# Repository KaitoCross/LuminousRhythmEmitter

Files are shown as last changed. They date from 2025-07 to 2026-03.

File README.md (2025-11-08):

# Future Gadget #16: Luminous Rhythm Emitter

## DIY Penlight project

### Description

This project is a work in progress! Use and build at your own risk! No guarantees given. Parts of the current version may be untested.
This project aims to create an open-source homemade penlight for various concerts (J-Pop, Idols, VTuber, Vocaloid) that can be controlled remotely. You'll need access to a 3D printer and equipment for soldering SMD parts. You'll have to order a PCB, based on the KiCad design provided in the `Circuits` folder, as well as some electronic parts. The `3D` folder contains the stl files for 3D printing. A parts list is located in the `Circuits` folder.

### Setup

[A brief How-To is located in `Circuits`](Circuits/README.md)

### Current Features

- Rechargable via USB-C
- Manual selection of LED color by pressing the button (cycling though a preset with 12 colors)
- Setting the color via (unsecured) Bluetooth Low Energy
- Separate Power Off switch

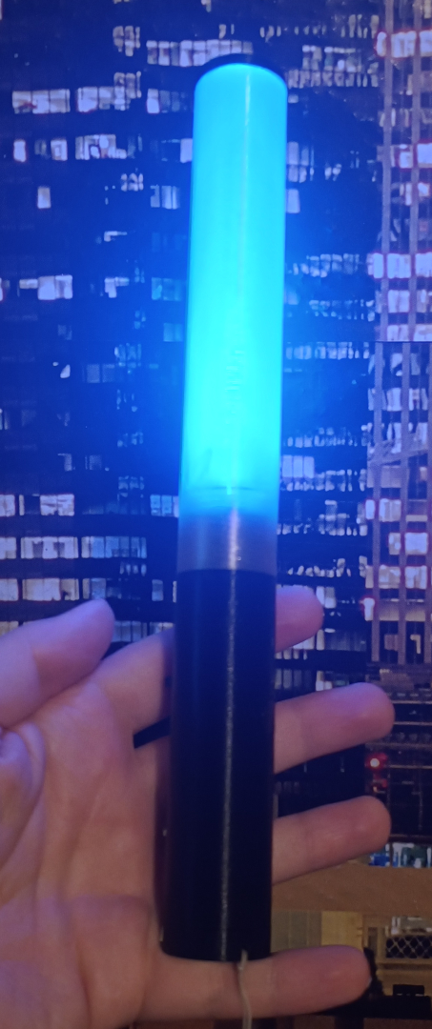
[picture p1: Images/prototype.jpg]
Prototype


### Shoutouts

Shoutouts to:

- rico132 (for helping with Fusion 360 and helping in fixing electronics)
- CaptainMeow (for the Otomo drawing on the PCB design)
- Dominik K (brainstormed the idea with me)
- KFP & the general VTubing community

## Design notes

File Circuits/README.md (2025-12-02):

# Hardware List:

- Seeed Studio XIAO ESP32C3
- power switch: MFP 120 by Knitter-Switch
- Any 18350 Li-ion battery with a **protection circuit** (preventing deep discharge)
- Button: generic 6x6x5mm pushbutton
- ~~20mm ø LED Lens (60°), max 11mm high~~
- screw the lens actually, it's better without
- The custom printed PCB
  - I recommend ordering the custom PCB through JLCPCB
- 2x 6-Pin 2.54mm Dupont female pin header (socket 8,5mm high)
- 2x 6-Pin 2.54mm Dupont male pin header (pin 6mm high)
- If PCB is not pre-assembled:
  - 1x Inolux IN-P55TATRGB
  - 3x S8050 (SMD type SOT-23)
  - SMD type 1206 resistors:
    - 3x 15,5 kOhm (or slightly lower)
    - 2x 11 Ohm (or slightly higher)
    - 1x 61 Ohm (or slightly higher)
- battery contacts (with spring)
- (optional) 100 mm 2,4 Ghz Antenna
- an LED light diffusion filter. Dimensions: 9,5cm x 14,5cm  (15.1mm inner cylinder radius)
  Recommendations: 
  - [Lee Colour Filter 251 (1/4 white diffusion)](https://www.thomann.de/intl/lee_colour_filter_251_q_w_diffus.htm)
  - [Lee Colour Filter 252 (1/8 white diffusion)](https://www.thomann.de/intl/lee_colour_filter_252_e_w_diffus.htm)

# How to Build

You’ll need to familiarize yourself with soldering SMD components.  
Required tools:

- SMD rework station

- Tweezers

- Solder paste and (preferably) no-clean flux

- Regular soldering iron and solder for through-hole parts

- [KiCAD](https://www.kicad.org/) (free & open-source) to open the circuit files

## XIAO ESP32C3

Start with the XIAO ESP32C3. Solder the male 6-pin headers to the board, aligning the 5V with the first pin of the pin header, with the long side of the pins on facing the same direction as the big chip. DO NOT USE 7-PIN headers! Solder the other male pin header exactly in parallel with the first one.s

## Custom PCB

Now you can start soldering the parts to the custom PCB. Start with the SMD parts, soldering them to their designated spots as marked on the board. Once that is done, solder the female pin headers to the board. They need to be on the side opposite to the LED.

## Battery wiring

Solder a red wire to the battery contact without the spring (positive battery pole). Thread the red wire through the centre hole of the 3D-printed battery wall. Then solder the other end of the red wire to the battery contact (positive pole) of the XIAO.

Solder a black wire to the negative battery contact pad of the XIAO. Solder the other end to the centre pin of the power switch. Solder another black wire from one of the outer pins of the power switch to the battery contact with the spring (negative). Ensure that this wire is long enough so that it can hang out of the bottom end (short thread) of the penlight case. Make it \~2 cm longer than the distance between USB port and bottom end.

## Pushbutton wiring

Connect two wires to the J4 holes on the PCB. Connect both wires to the pushbutton, one wire to the top right leg, the other one the the bottom right leg (see example image below)



## Assembly

3D-print all parts in the [`3D` folder](../3D). Print settings recommendations [are also provided.](../3D/print_settings.md) Some cutouts (mainly for the buttons) need to be sanded for a better fit.

Connect the PCB and the XIAO through the pin headers.

[Install the firmware on the XIAO](../Software/README.md) and test it.

Start with the half with the rectangular cutout on the top. Place the PCB on top of the Edge above the cutout, with the USB port facing the cutout. Place the black wire in the recess in the bottom. Then, but the battery wall in the space on the recess, aligning it with said recess, while the positive battery pole faces outward towards the bottom thread. 

To make working with the pushbutton easier, you need to straighten the unused legs, aligning them with the case of the button itself. Now, pull the pushbutton though the D-shaped hole, with the wires facing the wall. Place the button cap on the pushbutton. Put the rectangular power switch into it's holder near the XIAO.

Now, put the ~~lens~~ reflector into the ~~lens~~ reflector holder with the ~~flat~~ open side of the ~~lens~~ reflector facing the small end of the holder. Push it all the way in. Place the ~~lens~~ reflector holder on top of the PCB.

Now put the other half of the penlight base on top and close the case, making sure the buttons fit into the other half as well. Then you can screw on the top part. Into the top part, you can then place your light diffusion filter. You can then close the top part by screwing on the respective cap.

Now, you can place the battery in the battery compartment. Make sure that the positive pole faces inwards. The negative pole then faces outwards, and connects to the spring. hold the spring in place and close the battery compartment with the other, bigger cap.

Now you should be able to power on and use your penlight!

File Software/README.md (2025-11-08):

# Software

As a quick proof of concept, you can use [WLED](https://github.com/wled/WLED) to control the RGB LED on the ESP32 via WiFi. WLED does not offer Bluetooth support.
If you prefer Bluetooth Low Energy, I recommend [esphome](https://esphome.io). In this folder is an esphome sample configuration for the penlight hardware.
I prefer esphome simply because it offers Bluetooth Low Energy.
The sample configuration exposes a BLE characteristic that controls the LED. It expects an RGB value (3x 8 bit unsigned int) as input.
Currently, no verification & encryption of the communication is implemented as esphome does not support it yet. If there's demand (and if esphome doesnt implement it soon), I might write custom firmware with BLE security in the future.

A mobile companion app is planned. It's main purpose is to enable the remote controlling functionality. On one hand, the user should be able to control the colors manually through the app. On the other hand, the app should offer the possibility to hand off the control to a central lightjockey. The app would create the neccessary bridge for that.

## Firmware Setup

[Install esphome on your computer](https://esphome.io/guides/installing_esphome/)

Edit LRE.yaml and adjust it to your needs.

Afterwards, connect your Seeed Studio ESP32C3 to your computer via USB. Then run `esphome run C:/path/to/config/file/LRE.yaml`, changing the path to the LRE.yaml to the actual path on your computer. When the prompt `Found multiple options for uploading, please choose one:` appears, choose option 1 (USB JTAG/serial debug unit) and press enter. Then you're done.

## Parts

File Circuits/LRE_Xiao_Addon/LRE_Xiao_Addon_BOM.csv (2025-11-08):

Reference | Value | Datasheet | Footprint | Qty | DNP
D5 | Inolux_IN-P55TATRGB | https://www.inolux-corp.com/datasheet/SMDLED/RGB%20Top%20View/IN-P55TATRGB.pdf | LED_SMD:LED_Inolux_IN-P55TATRGB_PLCC6_5.0x5.5mm_P1.8mm | 1
J1,J3 | Conn_01x06_Socket | ~ | Connector_PinSocket_2.54mm:PinSocket_1x06_P2.54mm_Vertical | 2
Q1,Q2,Q3 | S8050 | https://mm.digikey.com/Volume0/opasdata/d220001/medias/docus/7158/5272_S8050.pdf | Package_TO_SOT_SMD:SOT-23 | 3
R1,R2,R3 | 15500 | ~ | Resistor_SMD:R_1206_3216Metric_Pad1.30x1.75mm_HandSolder | 3
R4,R6 | 5 | ~ | Resistor_SMD:R_1206_3216Metric_Pad1.30x1.75mm_HandSolder | 2
R5 | 65 | ~ | Resistor_SMD:R_1206_3216Metric_Pad1.30x1.75mm_HandSolder | 1

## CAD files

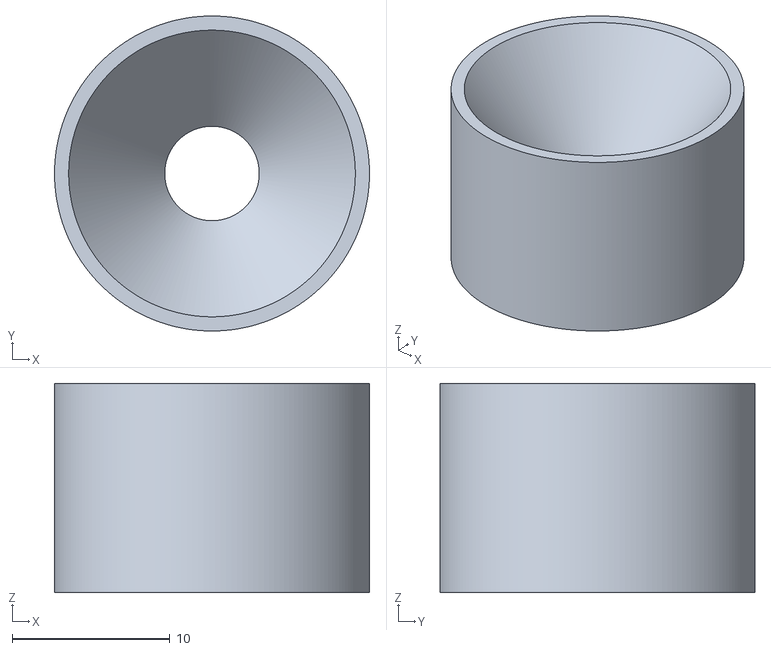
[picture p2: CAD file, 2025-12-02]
3D/LREReflector.stl
20.0 x 20.0 x 13.3

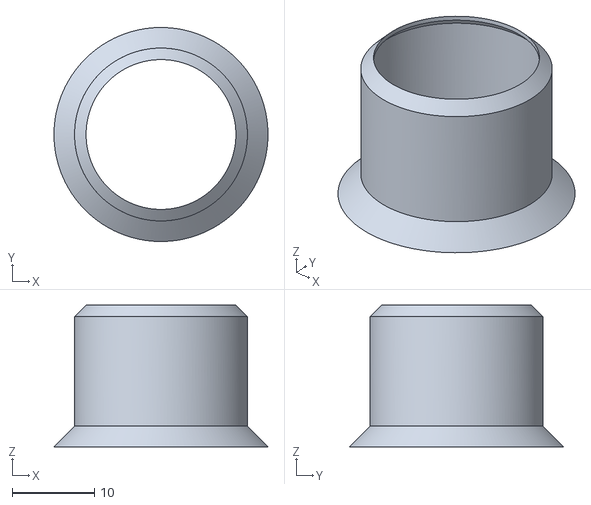
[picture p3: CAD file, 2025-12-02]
3D/LREReflectorHolder.stl
26.0 x 26.0 x 17.2

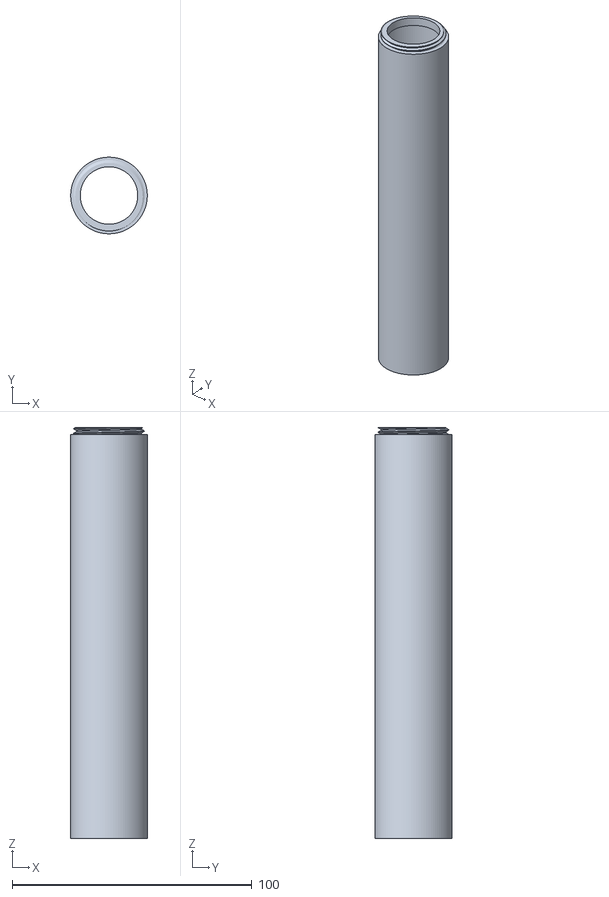
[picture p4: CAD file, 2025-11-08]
3D/LRETop.stl
32.0 x 32.0 x 171.6

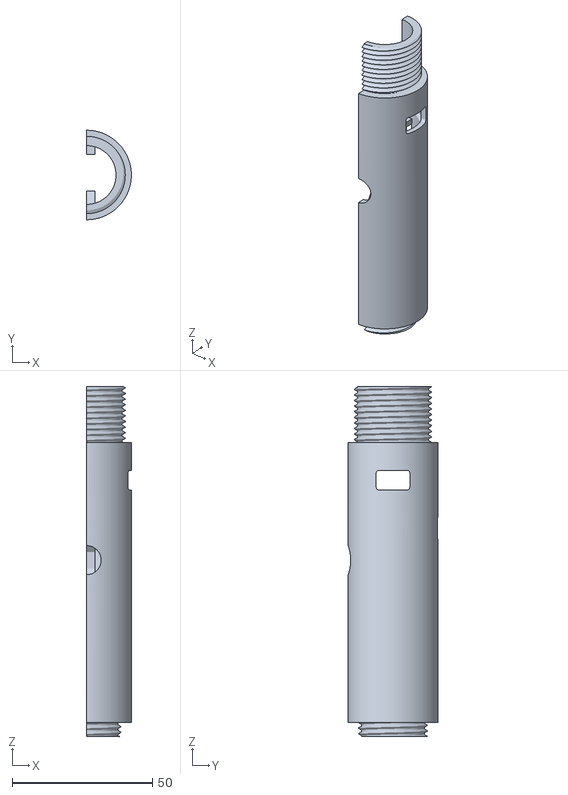
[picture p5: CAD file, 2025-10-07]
3D/LREBase2.stl
16.0 x 32.0 x 125.0

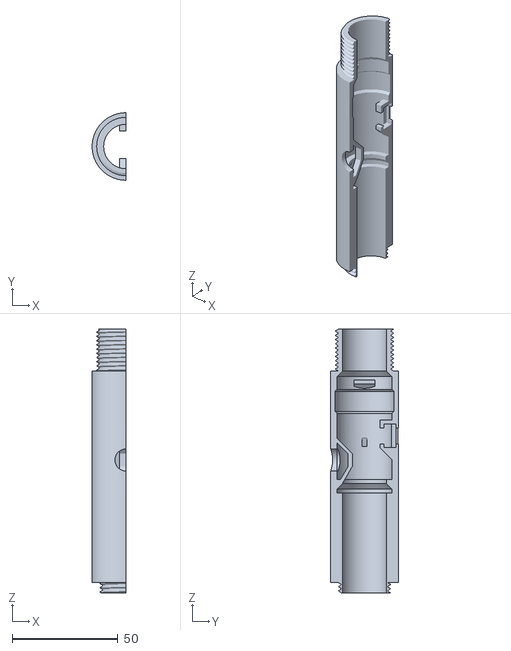
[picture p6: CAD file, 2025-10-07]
3D/LREBase1.stl
16.0 x 32.0 x 125.0

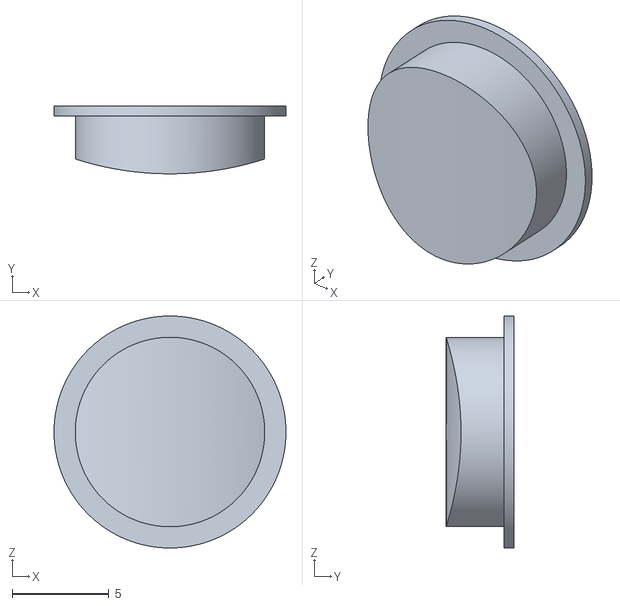
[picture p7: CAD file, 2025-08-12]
3D/LREButton.stl
12.0 x 3.50 x 12.0

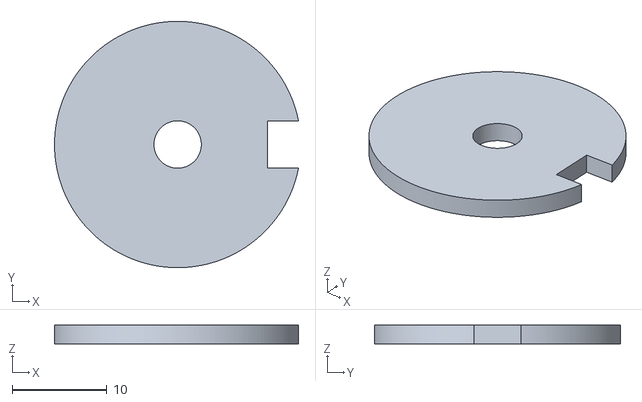
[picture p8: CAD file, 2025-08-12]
3D/LREBatteryWall.stl
25.8 x 26.0 x 2.00

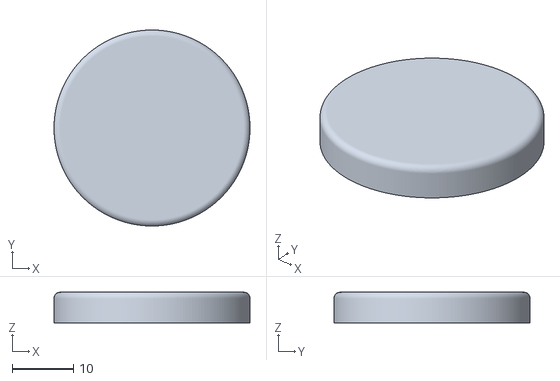
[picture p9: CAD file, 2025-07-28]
3D/LRETopCap.stl
32.0 x 32.0 x 5.00

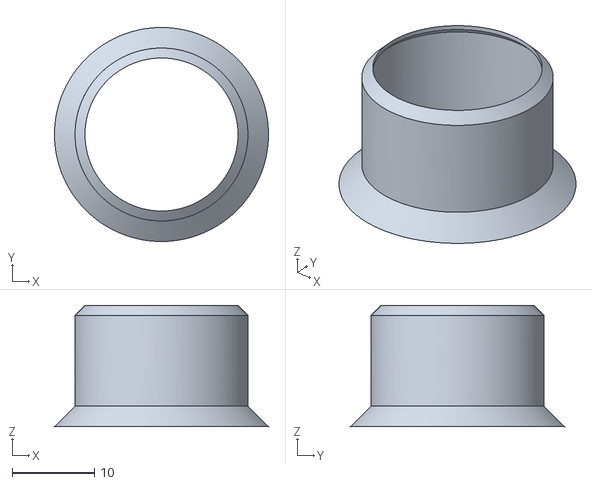
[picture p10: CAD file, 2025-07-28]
3D/LRELensHolderShort.stl
26.0 x 26.0 x 14.7

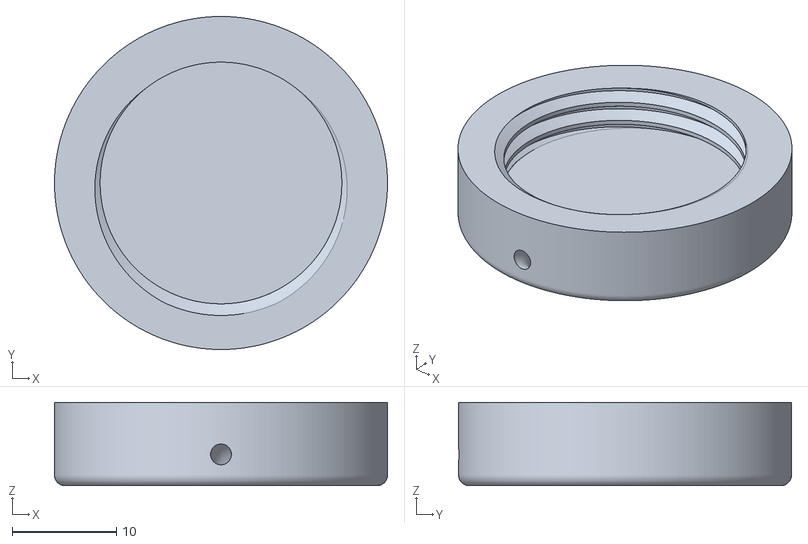
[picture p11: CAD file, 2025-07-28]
3D/LREBatteryCap.stl
32.0 x 32.0 x 8.00

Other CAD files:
CAD/LuminousRhythmEmitter.f3d

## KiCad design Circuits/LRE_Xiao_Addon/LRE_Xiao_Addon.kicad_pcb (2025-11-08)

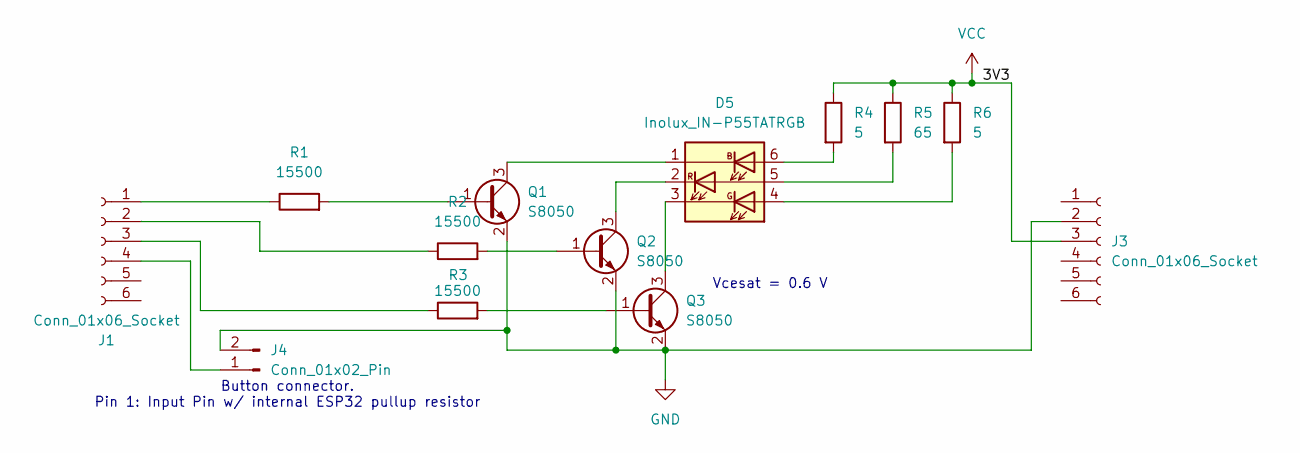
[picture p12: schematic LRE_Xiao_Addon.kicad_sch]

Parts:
D5: Inolux_IN-P55TATRGB; LED_Inolux_IN-P55TATRGB_PLCC6_5.0x5.5mm_P1.8mm
J1, J3: Conn_01x06_Socket; PinSocket_1x06_P2.54mm_Vertical
J4: Conn_01x02_Pin; PinHeader_1x02_P2.54mm_Vertical
Q1, Q2, Q3: S8050; SOT-23
R1, R2, R3: 15500; R_1206_3216Metric_Pad1.30x1.75mm_HandSolder
R4, R6: 5; R_1206_3216Metric_Pad1.30x1.75mm_HandSolder
R5: 65; R_1206_3216Metric_Pad1.30x1.75mm_HandSolder

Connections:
GND: J3.2, J4.2, Q1.2 (E), Q2.2 (E), Q3.2 (E)
unnamed: D5.6 (AB), R4.2
unnamed: D5.4 (AG), R6.2
unnamed: D5.5 (AR), R5.2
unnamed: D5.1 (KB), Q1.3 (C)
unnamed: D5.3 (KG), Q3.3 (C)
unnamed: D5.2 (KR), Q2.3 (C)
unnamed: J1.1, R1.1
unnamed: J1.2, R2.1
unnamed: J1.3, R3.1
unnamed: J1.4, J4.1
unnamed: Q1.1 (B), R1.2
unnamed: Q2.1 (B), R2.2
unnamed: Q3.1 (B), R3.2
VCC: J3.3, R4.1, R5.1, R6.1

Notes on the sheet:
Vcesat = 0.6 V
Button connector. Pin 1: Input Pin w/ internal ESP32 pullup resistor

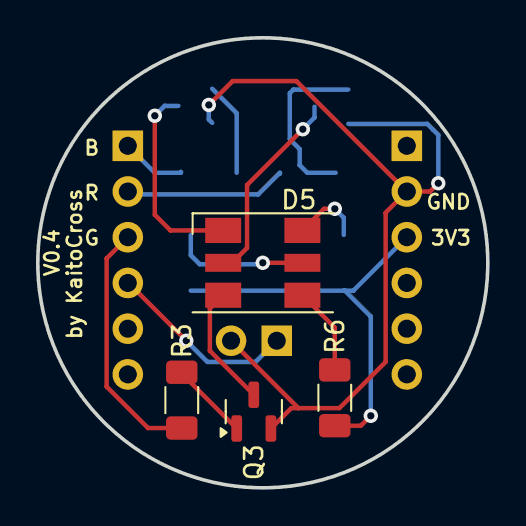
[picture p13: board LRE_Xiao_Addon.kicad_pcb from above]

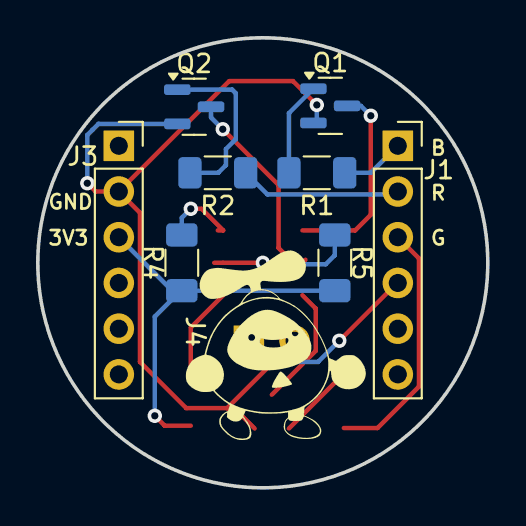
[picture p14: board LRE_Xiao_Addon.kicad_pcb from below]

Board: 2 copper layers, 25.0 x 25.0 mm, 13 parts (9 on the bottom side), 15 nets.

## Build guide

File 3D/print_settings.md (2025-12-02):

# Recommmended printing settings:

## for MK4S

### Base Parts, Buttons, Caps, Battery Wall

Filament: PLA or PETG. Cap for the tube: White

Base Profile: 0.20 mm STRUCTURAL @ MK4S 0.4

Support enabled

Infill 15%

External Perimeter 0.8mm or 0.9mm

Support width 0.36mm

Support Style: Grid (Prusa), Slim Tree (Orca)

Overhang Threshold: 0 (Prusa), 24 (Orca)

### Reflector & Reflector Holder

Filament: White PLA or PETG

Base Profile: 0.20 mm STRUCTURAL @ MK4S 0.4

Infill: 100%

Brim: none

Supports 0.36mm

### Top Tube

Filament: Transparent PETG

Base Profile: 0.20 mm STRUCTURAL @ MK4S 0.4

Supports: Only on build plate

Support Style: Grid (Prusa)

Top end of model on print bed

Seam position: Random

Fill pattern: concentric

Overhang Threshold: 0 (Prusa)

Speed of print moves: everything at 20 mm/s

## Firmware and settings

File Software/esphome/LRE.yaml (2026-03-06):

esphome:
  name: luminousrhythmemitter
  on_boot:
    priority: -100.0
    then:
     - lambda: |-
         auto curr_col = id(color_presets)[0];
         id(current_preset) = 1;
         auto r = (curr_col & 0xFF0000) >> 16;
         auto g = (curr_col & 0x00FF00) >> 8;
         auto b = (curr_col & 0x0000FF);
         auto call = id(pen_rgb).turn_on();
         call.set_rgb(static_cast<float>(r)/255.0,static_cast<float>(g)/255.0,static_cast<float>(b)/255.0);
         call.perform();

esp32:
  board: seeed_xiao_esp32c3
  framework:
    type: esp-idf

# Enable logging
logger:


# change password, set a custom one!
ota:
  - platform: esphome
    password: "password"

wifi: # If you want it to be available via WiFi, put your credentials here and set enable_on_boot to true
  enable_on_boot: false
  ssid: "WiFi"
  password: "password"
  reboot_timeout: 0s

  # Enable fallback hotspot (captive portal) in case wifi connection fails. Change password to custom one here as well
  ap:
    ssid: "luminousrhythmemitter"
    password: "password"
captive_portal:

globals:
   - id: color_presets # If you want more colors on your penlight, add them to initial_value as hex value and adjust the number in type (increasing or decreasing). Color 0x000000 turns off the LED
     type: int[13]
     restore_value: yes
     initial_value: '{0xff0000,0xff00e6,0xff91bf,0x00d1ff,0x00ff84,0xffff00,0xff0088,0x9e64ff,0x57ff00,0xff9844,0xffffff,0x003fff,0x000000}'
   - id: current_preset
     type: int
     restore_value: no
     initial_value: '0'

output:
  - platform: ledc
    pin: GPIO3
    id: led_r
    #Max percentage (66,66%) ^ gamma correction = max power
    #max_power: 90%
    
  - platform: ledc
    pin: GPIO4
    id: led_g
    max_power: 50%
    
  - platform: ledc
    pin: GPIO2
    id: led_b
    max_power: 65%

light:
  - platform: rgb
    name: "Penlight LED"
    id: pen_rgb
    gamma_correct: 2.8
    red: led_r
    green: led_g
    blue: led_b
    #color_correct: [0.66666666, 0.33333333, 1.0]

binary_sensor:
  - platform: gpio
    pin:
      number: GPIO5
      mode:
        input: true
        pullup: true
      inverted: true
    filters:
      - delayed_on_off: 30ms
      #- delayed_off: 30ms
    name: "LED Button"
    interrupt_type: ANY
    on_click:
    - min_length: 10s
      max_length: 15s
      then:
        - lambda: |-
            ESP_LOGD("binary_sensor", "lambda start");
        - wifi.enable:
    - min_length: 0s
      max_length: 2s
      then:
        - lambda: |-
            auto preset_len = sizeof(id(color_presets));
            auto var_len = sizeof(int);
            int curr = id(current_preset);
            id(current_preset) = ((curr + 1) % (preset_len/var_len));
            auto curr_col = id(color_presets)[curr];
            if (curr_col == 0) {
              auto call = id(pen_rgb).turn_off();
              call.perform();
            }
            else {
              auto r = (curr_col & 0xFF0000) >> 16;
              auto g = (curr_col & 0x00FF00) >> 8;
              auto b = (curr_col & 0x0000FF);
              auto call = id(pen_rgb).turn_on();
              call.set_rgb(static_cast<float>(r)/255.0,static_cast<float>(g)/255.0,static_cast<float>(b)/255.0);
              call.perform();
            }
          

esp32_ble_server:
  manufacturer: "KaitoCross"
  model: "Luminous Rhythm Emitter"
  services:
    - uuid: 759297ad-ad74-4eb2-af4b-d94332ec6b7d
      advertise: true
      characteristics:
       - uuid: b4cb7b26-407c-4040-b992-00325d97f517
         write: true
         value:
           data: [255,255,255]
         on_write:
           then:
            - lambda: |-
                  float red = 0.0f;
                  float green = 0.0f;
                  float blue = 0.0f;

                  if (x.size() >= 3) {
                    int imod = 0;
                    if (x.size() == 4){ // why. Linux BT GATTTOOL sends 4 bytes. First is zero. smh.
                      imod = 1;
                    }
                    if (x[0+imod] > 0)
                      red = x[0+imod] / 255.0f;
                    if (x[1+imod] > 0)
                      green = x[1+imod] / 255.0f;
                    if (x[2+imod] > 0)
                      blue = x[2+imod] / 255.0f;
                  }
                  if ((red == 0.0f) && (green == 0.0f) && (blue == 0.0f)) {
                    auto call = id(pen_rgb).turn_off();
                    call.perform();
                  }
                  else {
                    auto call = id(pen_rgb).turn_on();
                    call.set_rgb(red, green, blue);
                    call.perform();
                  }
            - lambda: |-
                  ESP_LOGD("ble", "Received BLE data (length: %d):", x.size());
                  for (int i = 0; i < x.size(); i++) {
                    ESP_LOGD("ble", "Byte %d: 0x%02X", i, x[i]);
                  }

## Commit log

2025-07-29 updated resistors
    [LRE_Xiao_Addon.kicad_sch]
2025-08-12 USB Port accessible, updated color scheme
    [LREBase1.stl, LREBase2.stl, LREBatteryWall.stl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]
2025-08-14 widened button hole & USB port
    [LREBase1.stl, LREBase2.stl, LuminousRhythmEmitter.f3d]
2025-08-14 fix color wheel, activate LED on startup
    [LRE.yaml]
2025-08-16 widened top thread for stability
    [LREBase1.stl, LREBase2.stl, LRETop.stl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]
2025-09-23 adjusted hole for power slider
    [LREBase1.stl, LREBase2.stl, LuminousRhythmEmitter.f3d]
2025-10-07 random update
    [LREBase1.stl, LREBase2.stl, LuminousRhythmEmitter.f3d]
2025-10-12 PCB update
    [LRE_Xiao_Addon.kicad_pcb]
2025-10-30 Documentation update, Bugfix esphome conf
    [LRE.yaml]
2025-10-31 Documentation Update
    [LRELensHolder.stl]
2025-11-08 added documentation
    [LRE_Xiao_Addon.kicad_pcb]
2025-11-08 Bill of Materials for PCB added
    [LRE_Xiao_Addon_BOM.csv]
2025-11-08 Documentation + 3D model update
    [LRELensHolderShort.stl, LRETop.stl]
2025-11-09 adjust resistors
    [LRE_Xiao_Addon.kicad_sch]
2025-11-11 update hardware info
    [LRE_Xiao_Addon.kicad_sch]
2025-11-14 CAD changes
    [LuminousRhythmEmitter.f3d]
2025-12-02 replace lens with "reflector"
    [LREReflector.stl, LREReflectorHolder.stl, LuminousRhythmEmitter.f3d]
